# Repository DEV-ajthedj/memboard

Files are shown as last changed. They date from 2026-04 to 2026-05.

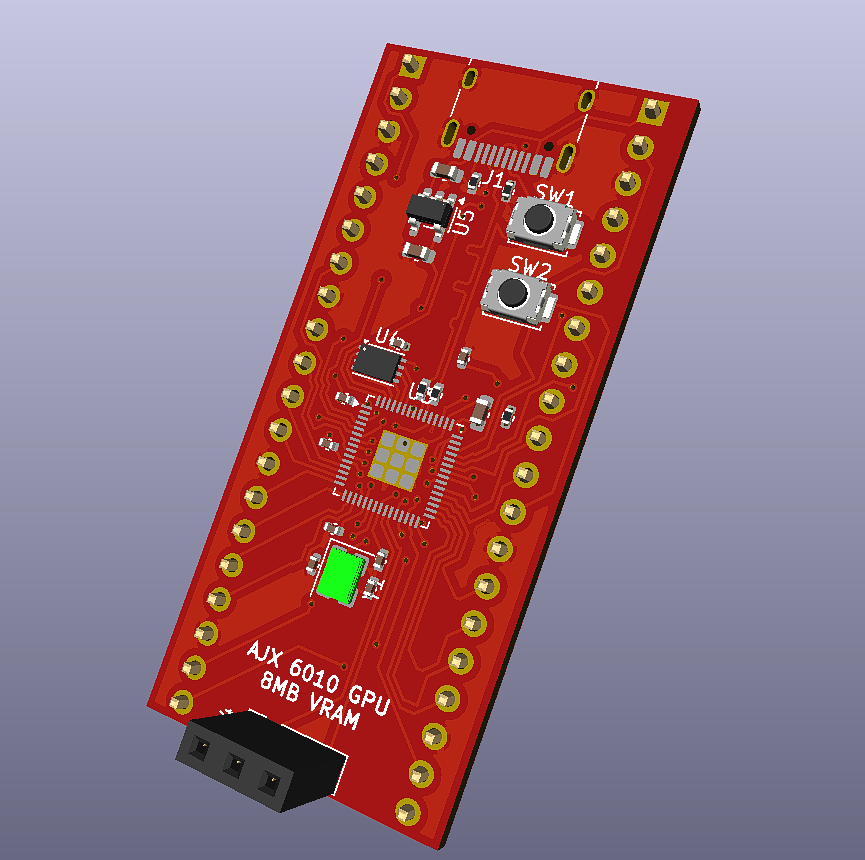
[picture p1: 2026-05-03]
memboard.png

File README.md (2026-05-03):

# memboard
A custom development board aimed at maximizing the RAM of an RP2354A. I am doing this because I am currently developing a 3D graphics pipeline (very experimental) for microcontrollers, and an upgrade from the 264 KB Pico would be very nice for larger frambuffers and 3D objects. This is also why I didn't really need much flash on the board, so I just went with the RP2354A, which has 2MB of flash already built in. This project is meant for me to be able to really start developing and testing my pipeline more, without being limited by memory.

# Future Improvements
In the future, I hope to make firmware to make this microcontroller stackable. This could (hopefully) substantially increase the maximum compute it could generate.

# Preview



# Routing


# Schematic


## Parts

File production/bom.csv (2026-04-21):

Designator | Footprint | Quantity | Value | LCSC Part #
C1, C24 | 0402 | 2 | 1uF
C10, C2, C22, C23, C3, C4, C5, C6, C7, C8, C9 | 0402 | 11 | 0.1uF
C13, C14 | 0603 | 2 | 10uF
C15, C16 | 0402 | 2 | 33pF
C18, C19, C20, C21 | 0603 | 4 | 4.7uF
J1 | USB_C_Receptacle_HRO_TYPE-C-31-M-12 | 1 | USB_C_Receptacle_USB2.0_14P
J2, J3 | PinHeader_1x20_P2.54mm_Vertical | 2 | Conn_01x20_Pin
J4 | PinSocket_1x03_P2.54mm_Vertical | 1 | Conn_01x03_Socket
L1 | 0805 | 1 | 3.3uH
R1, R2 | 0402 | 2 | 5.1k
R10, R9 | 0402 | 2 | 27
R5, R7 | 0402 | 2 | 1k
R6 | 0402 | 1 | 10k
R8 | 0402 | 1 | 33
SW1, SW2 | SW_Push_SPST_NO_Alps_SKRK | 2 | SW_Push
U3 | QFN-60-1EP_7x7mm_P0.4mm_EP3.4x3.4mm | 1 | RP2354A
U4 | Winbond_USON-8-1EP_3x2mm_P0.5mm_EP0.2x1.6mm | 1 | APS6404L-3SQRx-ZR
U5 | SOT-23-5 | 1 | AP2112K-3.3
Y1 | Crystal_SMD_3225-4Pin_3.2x2.5mm | 1 | 12 MHz

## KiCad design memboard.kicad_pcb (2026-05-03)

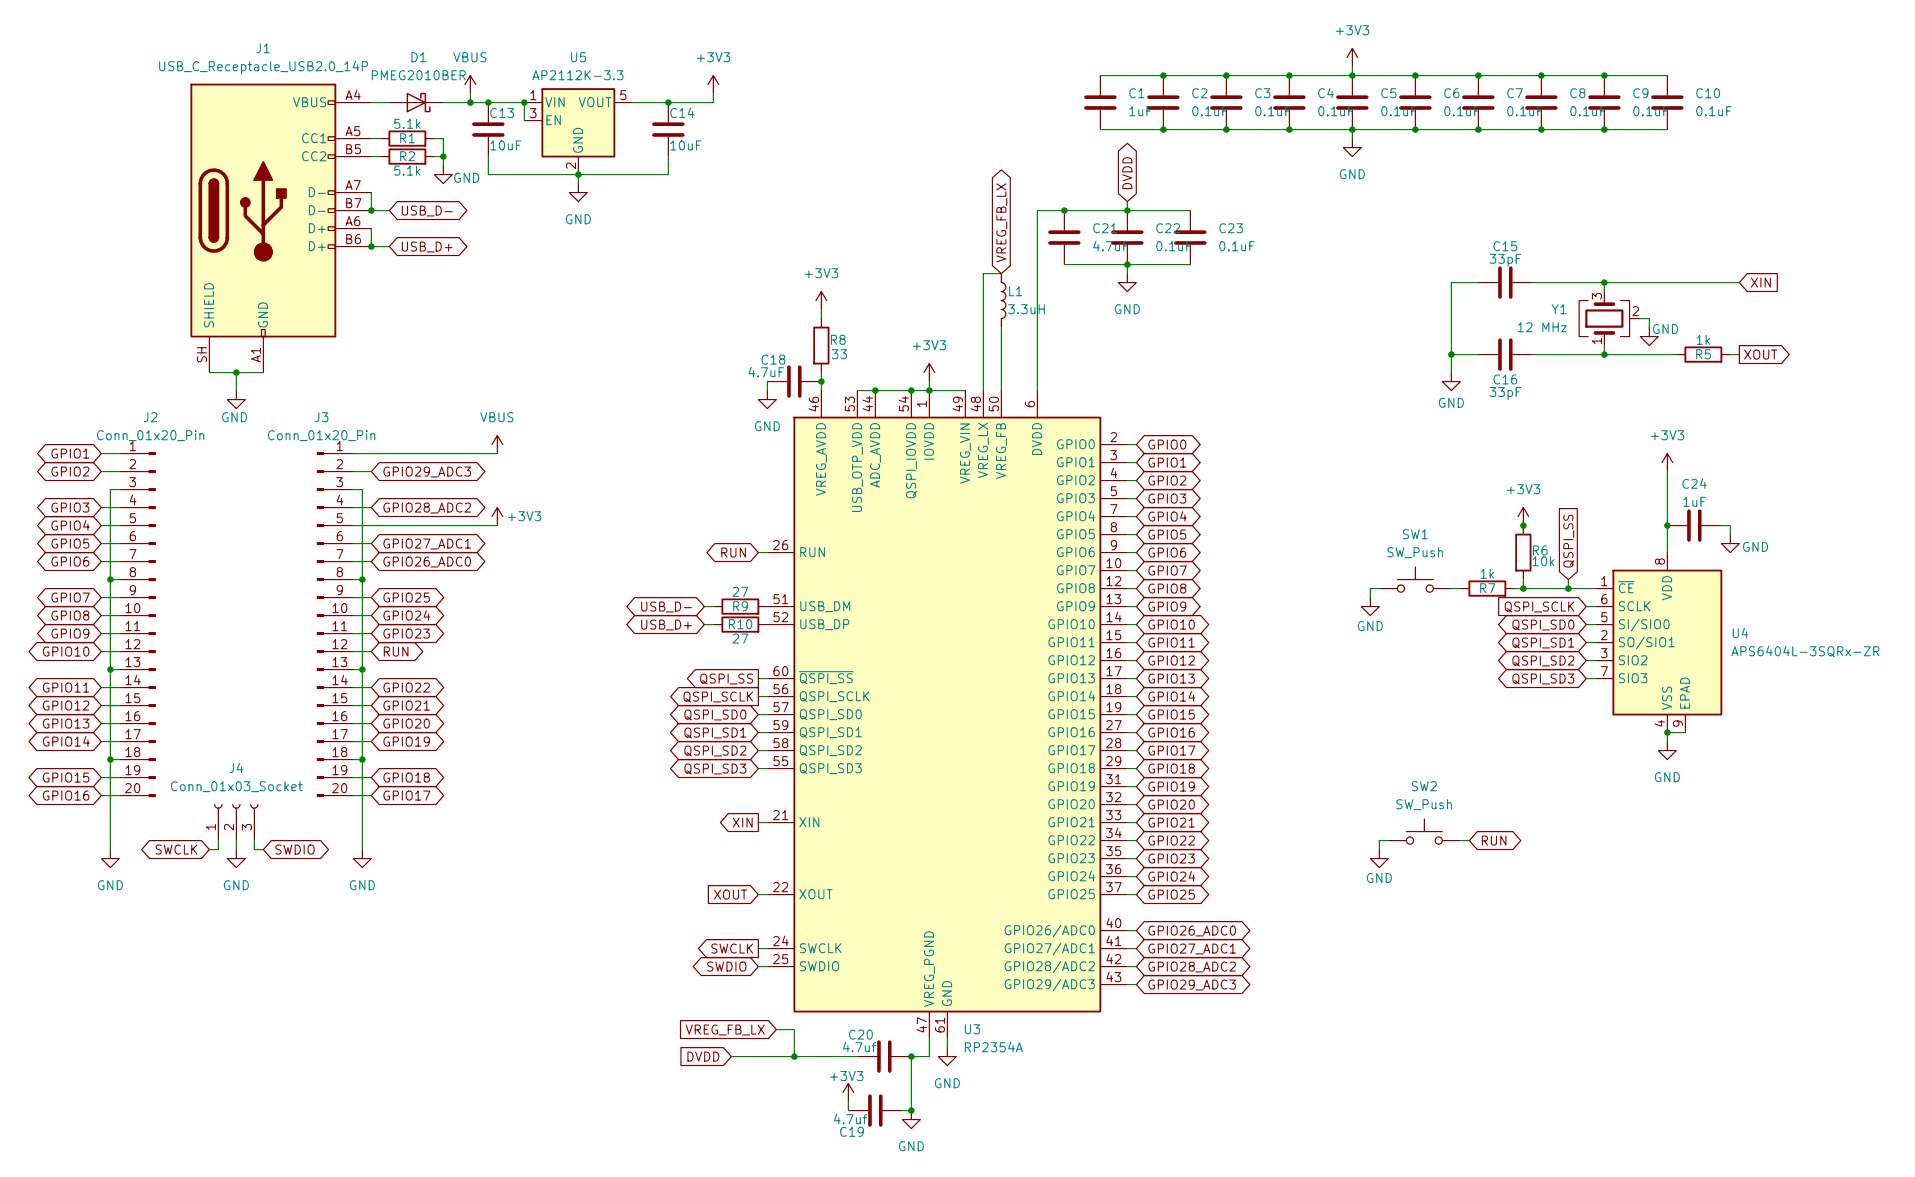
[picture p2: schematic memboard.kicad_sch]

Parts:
C1, C24: 1uF; C_0402_1005Metric
C2, C3, C4, C5, C6, C7, C8, C9, C10, C22, C23: 0.1uF; C_0402_1005Metric
C13, C14: 10uF; C_0603_1608Metric
C15, C16: 33pF; C_0402_1005Metric
C18, C21: 4.7uF; C_0603_1608Metric
C19, C20: 4.7uf; C_0603_1608Metric
D1: PMEG2010BER; Nexperia_CFP3_SOD-123W
J1: USB_C_Receptacle_USB2.0_14P; USB_C_Receptacle_HRO_TYPE-C-31-M-12
J2, J3: Conn_01x20_Pin; PinHeader_1x20_P2.54mm_Vertical
J4: Conn_01x03_Socket; PinSocket_1x03_P2.54mm_Vertical
L1: 3.3uH; L_0805_2012Metric
R1, R2: 5.1k; R_0402_1005Metric
R5, R7: 1k; R_0402_1005Metric
R6: 10k; R_0402_1005Metric
R8: 33; R_0402_1005Metric
R9, R10: 27; R_0402_1005Metric
SW1, SW2: SW_Push; SW_Push_SPST_NO_Alps_SKRK
U3: RP2354A; QFN-60-1EP_7x7mm_P0.4mm_EP3.4x3.4mm
U4: APS6404L-3SQRx-ZR; Winbond_USON-8-1EP_3x2mm_P0.5mm_EP0.2x1.6mm
U5: AP2112K-3.3; SOT-23-5
Y1: 12 MHz; Crystal_SMD_3225-4Pin_3.2x2.5mm

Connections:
+3V3: C1.1, C2.1, C3.1, C4.1, C5.1, C6.1, C7.1, C8.1, C9.1, C10.1, C14.1, C19.1, C24.1, J3.5, R6.1, R8.1, U3.1 (IOVDD), U3.11 (IOVDD), U3.20 (IOVDD), U3.30 (IOVDD), U3.38 (IOVDD), U3.44 (ADC_AVDD), U3.45 (IOVDD), U3.49 (VREG_VIN), U3.53 (USB_OTP_VDD), U3.54 (QSPI_IOVDD), U4.8 (VDD), U5.5 (VOUT)
DVDD: C20.1, C21.1, C22.1, C23.1, L1.1, U3.6 (DVDD), U3.23 (DVDD), U3.39 (DVDD), U3.48 (VREG_LX)
GND: C1.2, C2.2, C3.2, C4.2, C5.2, C6.2, C7.2, C8.2, C9.2, C10.2, C13.2, C14.2, C15.1, C16.1, C18.1, C19.2, C20.2, C21.2, C22.2, C23.2, C24.2, J1.A1 (GND), J1.A12 (GND), J1.B1 (GND), J1.B12 (GND), J1.SH (SHIELD), J2.3, J2.8, J2.13, J2.18, J3.3, J3.8, J3.13, J3.18, J4.2, R1.2, R2.2, SW1.1, SW2.1, U3.47 (VREG_PGND), U3.61 (GND), U4.4 (VSS), U4.9 (EPAD), U5.2 (GND), Y1.2 (G), Y1.4 (G)
GPIO0: U3.2 (GPIO0)
GPIO1: J2.1, U3.3 (GPIO1)
GPIO2: J2.2, U3.4 (GPIO2)
GPIO3: J2.4, U3.5 (GPIO3)
GPIO4: J2.5, U3.7 (GPIO4)
GPIO5: J2.6, U3.8 (GPIO5)
GPIO6: J2.7, U3.9 (GPIO6)
GPIO7: J2.9, U3.10 (GPIO7)
GPIO8: J2.10, U3.12 (GPIO8)
GPIO9: J2.11, U3.13 (GPIO9)
GPIO10: J2.12, U3.14 (GPIO10)
GPIO11: J2.14, U3.15 (GPIO11)
GPIO12: J2.15, U3.16 (GPIO12)
GPIO13: J2.16, U3.17 (GPIO13)
GPIO14: J2.17, U3.18 (GPIO14)
GPIO15: J2.19, U3.19 (GPIO15)
GPIO16: J2.20, U3.27 (GPIO16)
GPIO17: J3.20, U3.28 (GPIO17)
GPIO18: J3.19, U3.29 (GPIO18)
GPIO19: J3.17, U3.31 (GPIO19)
GPIO20: J3.16, U3.32 (GPIO20)
GPIO21: J3.15, U3.33 (GPIO21)
GPIO22: J3.14, U3.34 (GPIO22)
GPIO23: J3.11, U3.35 (GPIO23)
GPIO24: J3.10, U3.36 (GPIO24)
GPIO25: J3.9, U3.37 (GPIO25)
GPIO26_ADC0: J3.7, U3.40 (GPIO26/ADC0)
GPIO27_ADC1: J3.6, U3.41 (GPIO27/ADC1)
GPIO28_ADC2: J3.4, U3.42 (GPIO28/ADC2)
GPIO29_ADC3: J3.2, U3.43 (GPIO29/ADC3)
unnamed: C16.2, R5.1, Y1.1
unnamed: D1.2 (A), J1.A4 (VBUS), J1.A9 (VBUS), J1.B4 (VBUS), J1.B9 (VBUS)
unnamed: J1.A5 (CC1), R1.1
unnamed: J1.B5 (CC2), R2.1
unnamed: R7.1, SW1.2
unnamed: R9.2, U3.51 (USB_DM)
unnamed: R10.2, U3.52 (USB_DP)
unnamed: C18.2, R8.2, U3.46 (VREG_AVDD)
unnamed: L1.2, U3.50 (VREG_FB)
QSPI_SCLK: U3.56 (QSPI_SCLK), U4.6 (SCLK)
QSPI_SD0: U3.57 (QSPI_SD0), U4.5 (SI/SIO0)
QSPI_SD1: U3.59 (QSPI_SD1), U4.2 (SO/SIO1)
QSPI_SD2: U3.58 (QSPI_SD2), U4.3 (SIO2)
QSPI_SD3: U3.55 (QSPI_SD3), U4.7 (SIO3)
QSPI_SS: R6.2, R7.2, U3.60 (~QSPI_SS), U4.1 (~CE)
RUN: J3.12, SW2.2, U3.26 (RUN)
SWCLK: J4.1, U3.24 (SWCLK)
SWDIO: J4.3, U3.25 (SWDIO)
USB_D+: J1.A6 (D+), J1.B6 (D+), R10.1
USB_D-: J1.A7 (D-), J1.B7 (D-), R9.1
VBUS: C13.1, D1.1 (K), J3.1, U5.1 (VIN), U5.3 (EN)
XIN: C15.2, U3.21 (XIN), Y1.3
XOUT: R5.2, U3.22 (XOUT)

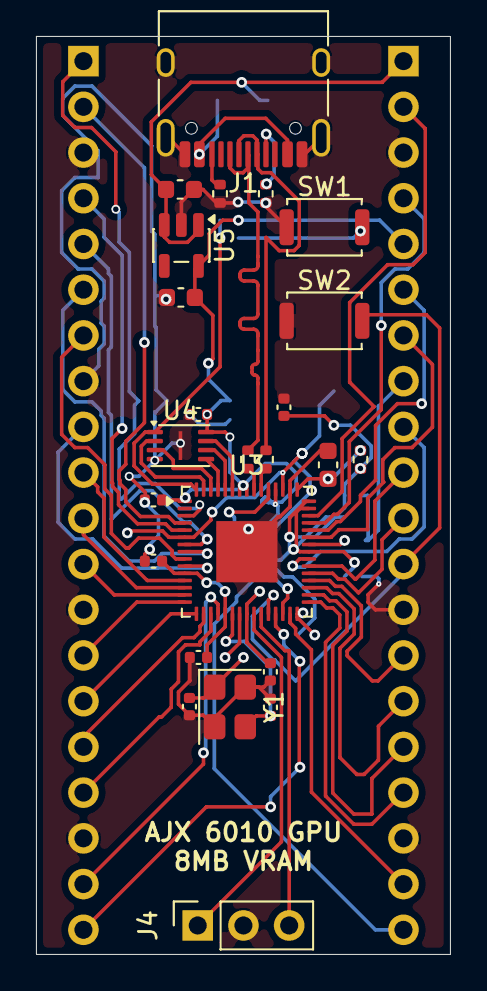
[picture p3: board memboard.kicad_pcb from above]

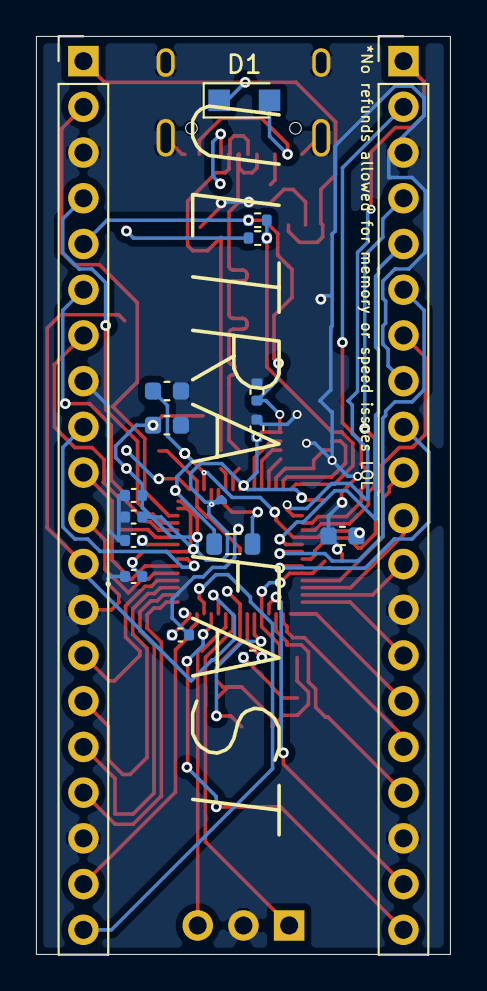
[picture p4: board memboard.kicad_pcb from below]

Board: 4 copper layers, 23.0 x 51.0 mm, 41 parts (17 on the bottom side), 55 nets.

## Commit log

2026-04-21 Finished Design
    [bom.csv, designators.csv, memboard.kicad_pcb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]
2026-04-24 Add schematic image to README
2026-05-03 Added a Schottky diode to allow power through VBUS because USB-C cannot be back powered
    [memboard.kicad_pcb, memboard.kicad_sch]
